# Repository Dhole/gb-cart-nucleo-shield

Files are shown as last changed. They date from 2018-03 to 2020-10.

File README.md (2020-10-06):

# Game Boy Cart NUCLEO Shield

## Description

This is the design of a Shield for NUCLEO STM32 development boards (also known
as STM32 NUCLEO Morpho) to connect Game Boy cartridges.

This PCB is meant to be used with my Game Boy Cart reader/writer:

- [gb-rw-stm32f411](https://github.com/Dhole/gb-rw-stm32f411)
- [gb-rw-host](https://github.com/Dhole/gb-rw-host)

## Pictures

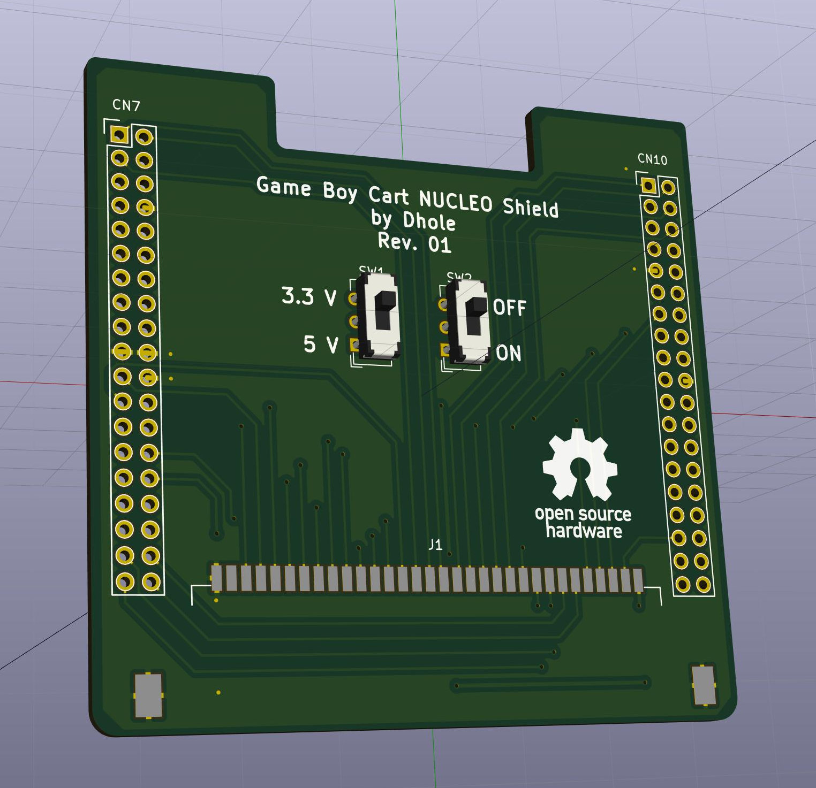
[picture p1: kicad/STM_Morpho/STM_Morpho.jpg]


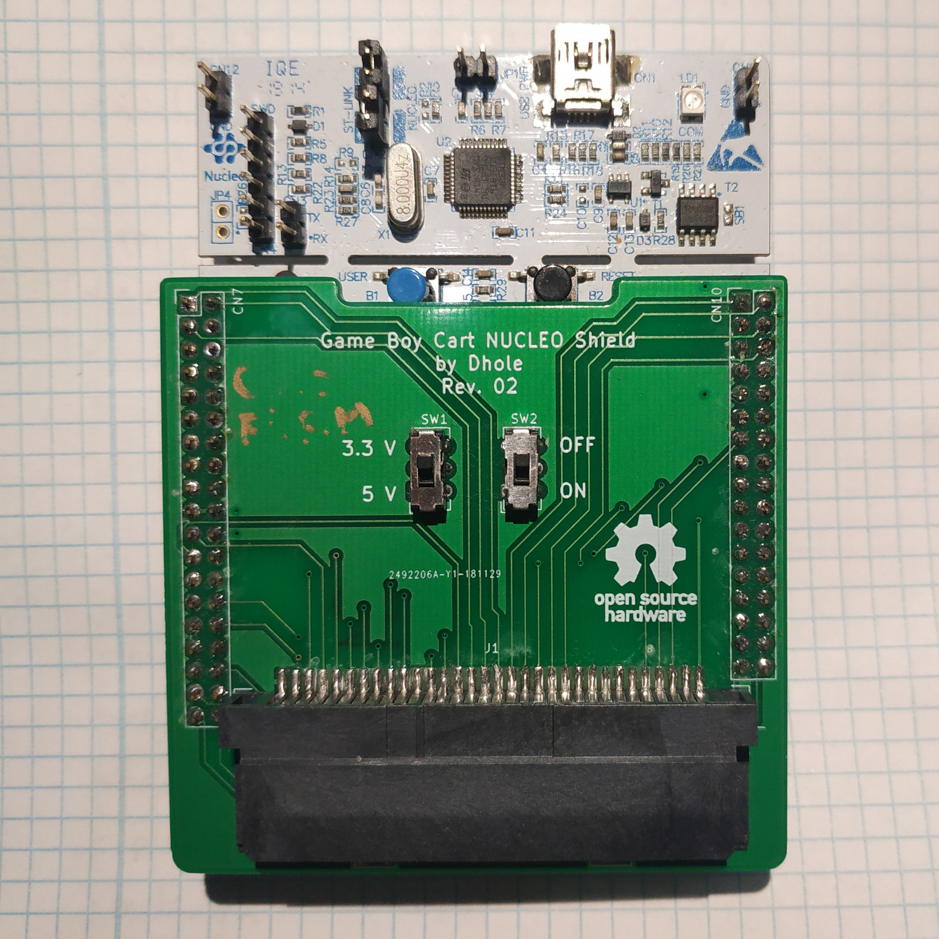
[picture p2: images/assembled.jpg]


## Components

Prices are estimations taken from AliExpress (except when stated explicitly)

- 2 x 6 pin toggle switch (~ 2 x 1.3 EUR / 10)

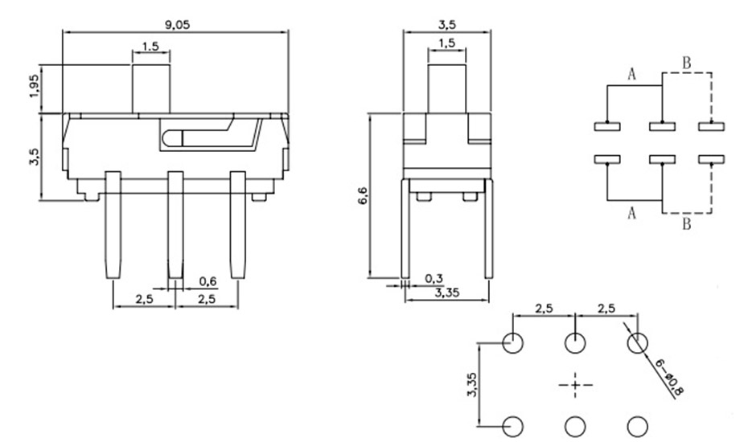
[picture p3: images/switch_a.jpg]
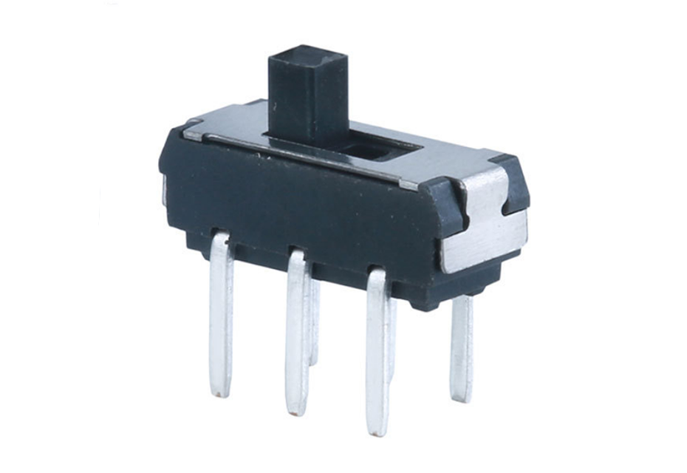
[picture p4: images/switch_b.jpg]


- 2 x 40 pin header connector strip, 2.54m spacing (~ 2 x 1.03 EUR / 10)
  - You will need to cut the strips into: 2 x 17 pins, 2 x 19 pins

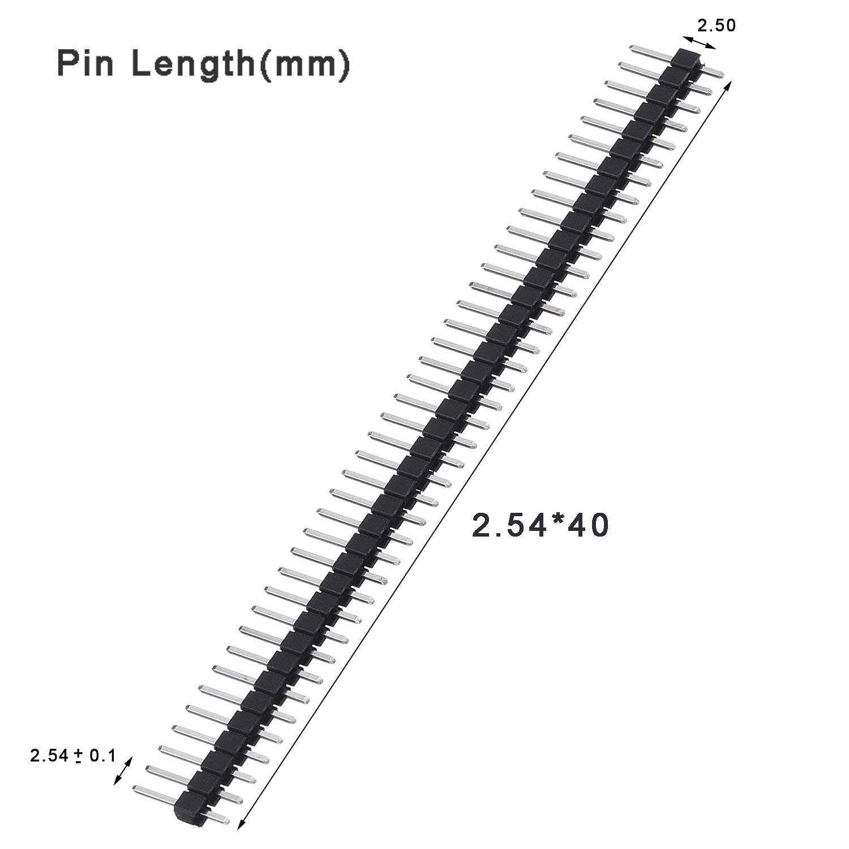
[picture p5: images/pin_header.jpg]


- 1 x GBA slot (~ 1 x 7.02 EUR / 5)

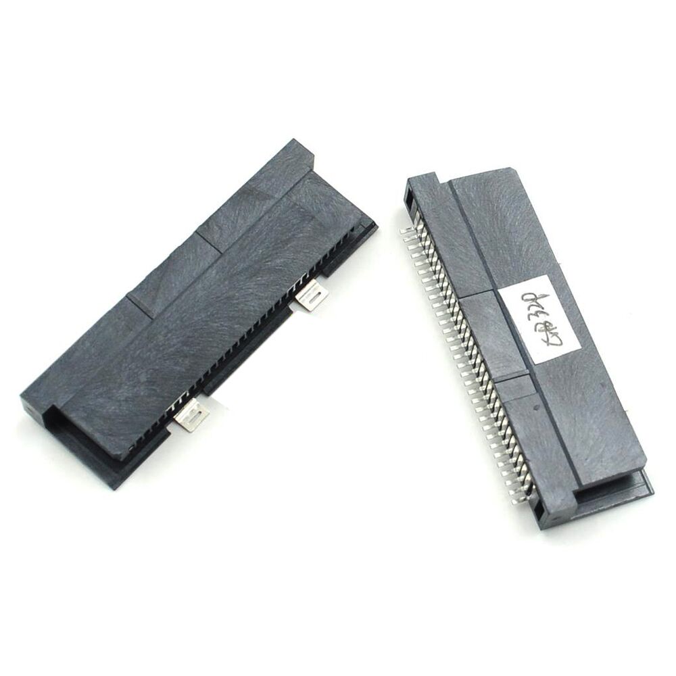
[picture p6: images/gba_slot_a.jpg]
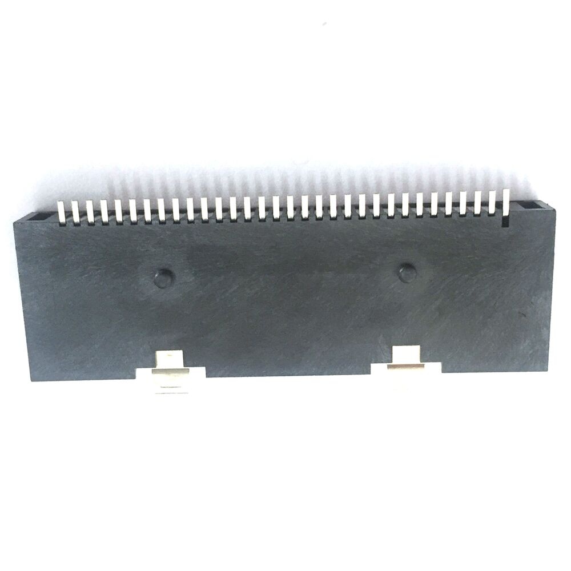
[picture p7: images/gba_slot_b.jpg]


The firmware is implemented to work on the NUCLEO-F411RE

- 1 x NUCLEO-F411RE (1 x 11.48 EUR at [eu.mouser.com](https://eu.mouser.com))

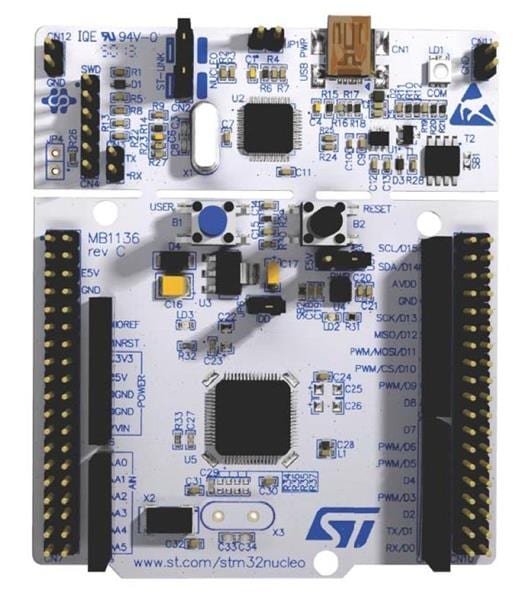
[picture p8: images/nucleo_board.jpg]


I ordered the manufacture of the board at JLCPCB with great results
- 1 x 2 layer PCB board (~ 1 x 10 EUR / 10 with shipping included in 2018)

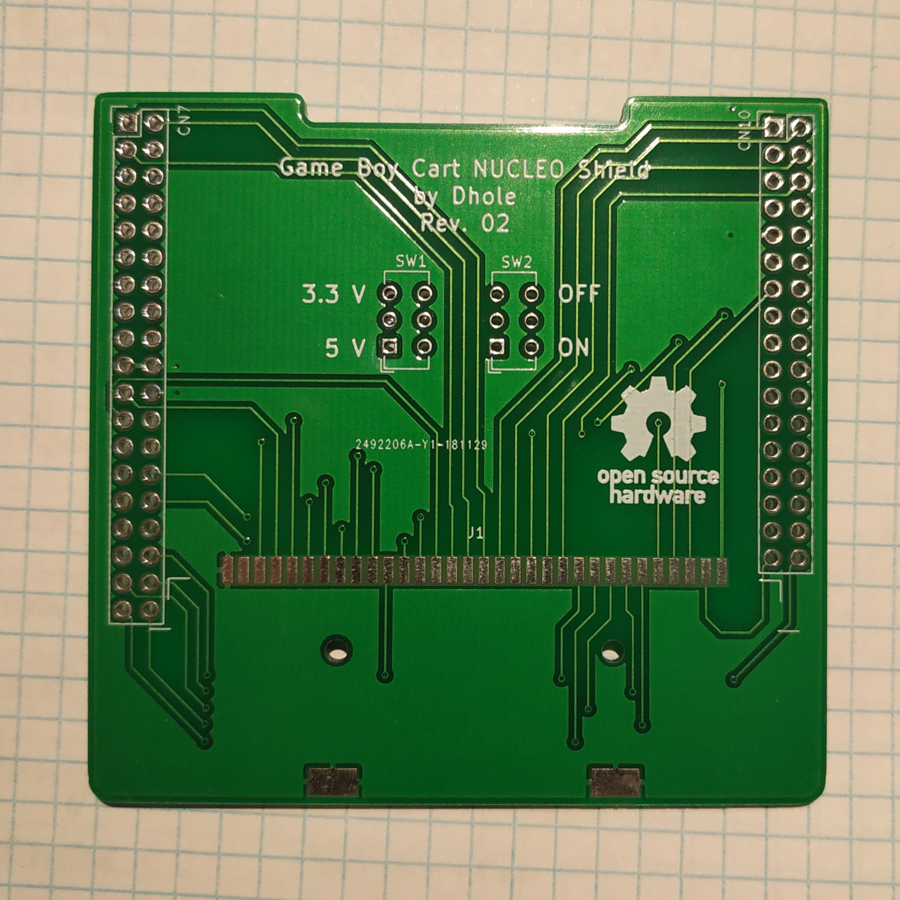
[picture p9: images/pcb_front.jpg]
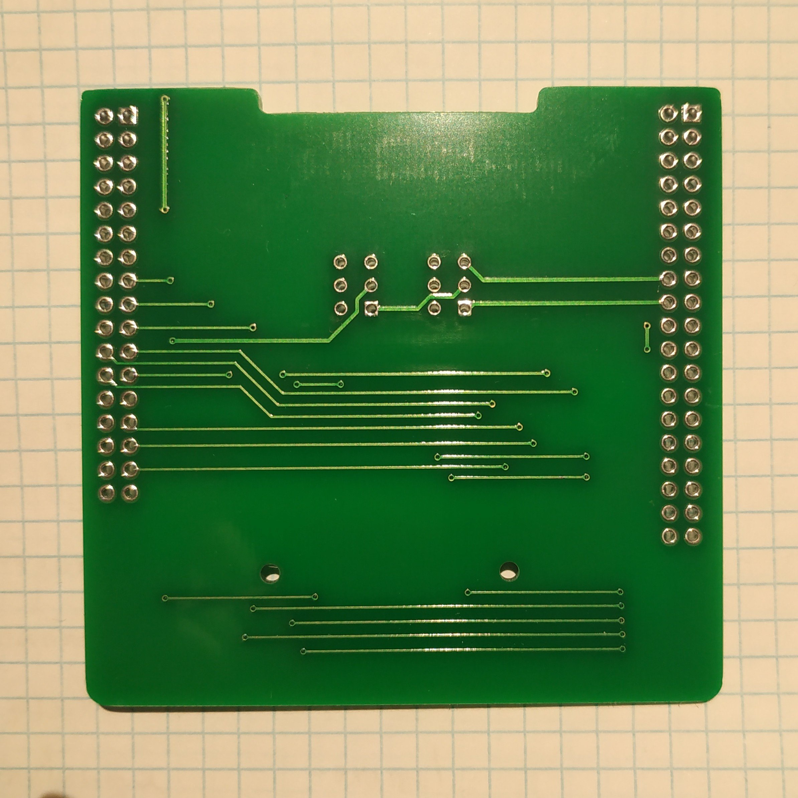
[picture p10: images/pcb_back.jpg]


## Attributions

The design this PCB is based on an [STM32 NUCLEO Morpho template made by
mobilinkd](https://github.com/mobilinkd/stm-morpho-template) published under
the MIT License.

The Game Boy cartridge slot component used in the PCB is taken from the [KiCad libraries by gekkio](https://github.com/Gekkio/gekkio-kicad-libs) published under the 
[Creative Commons Attribution license](https://creativecommons.org/licenses/by/4.0/)

## License

I'm publishing the rest of the work under the [Creative Commons Attribution-ShareAlike license](https://creativecommons.org/licenses/by-sa/4.0/).



**CC BY-SA**

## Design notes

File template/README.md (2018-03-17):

# stm-morpho-template

https://github.com/mobilinkd/stm-morpho-template

KiCad Template for STM32 Nucleo-64 Expansion Boards

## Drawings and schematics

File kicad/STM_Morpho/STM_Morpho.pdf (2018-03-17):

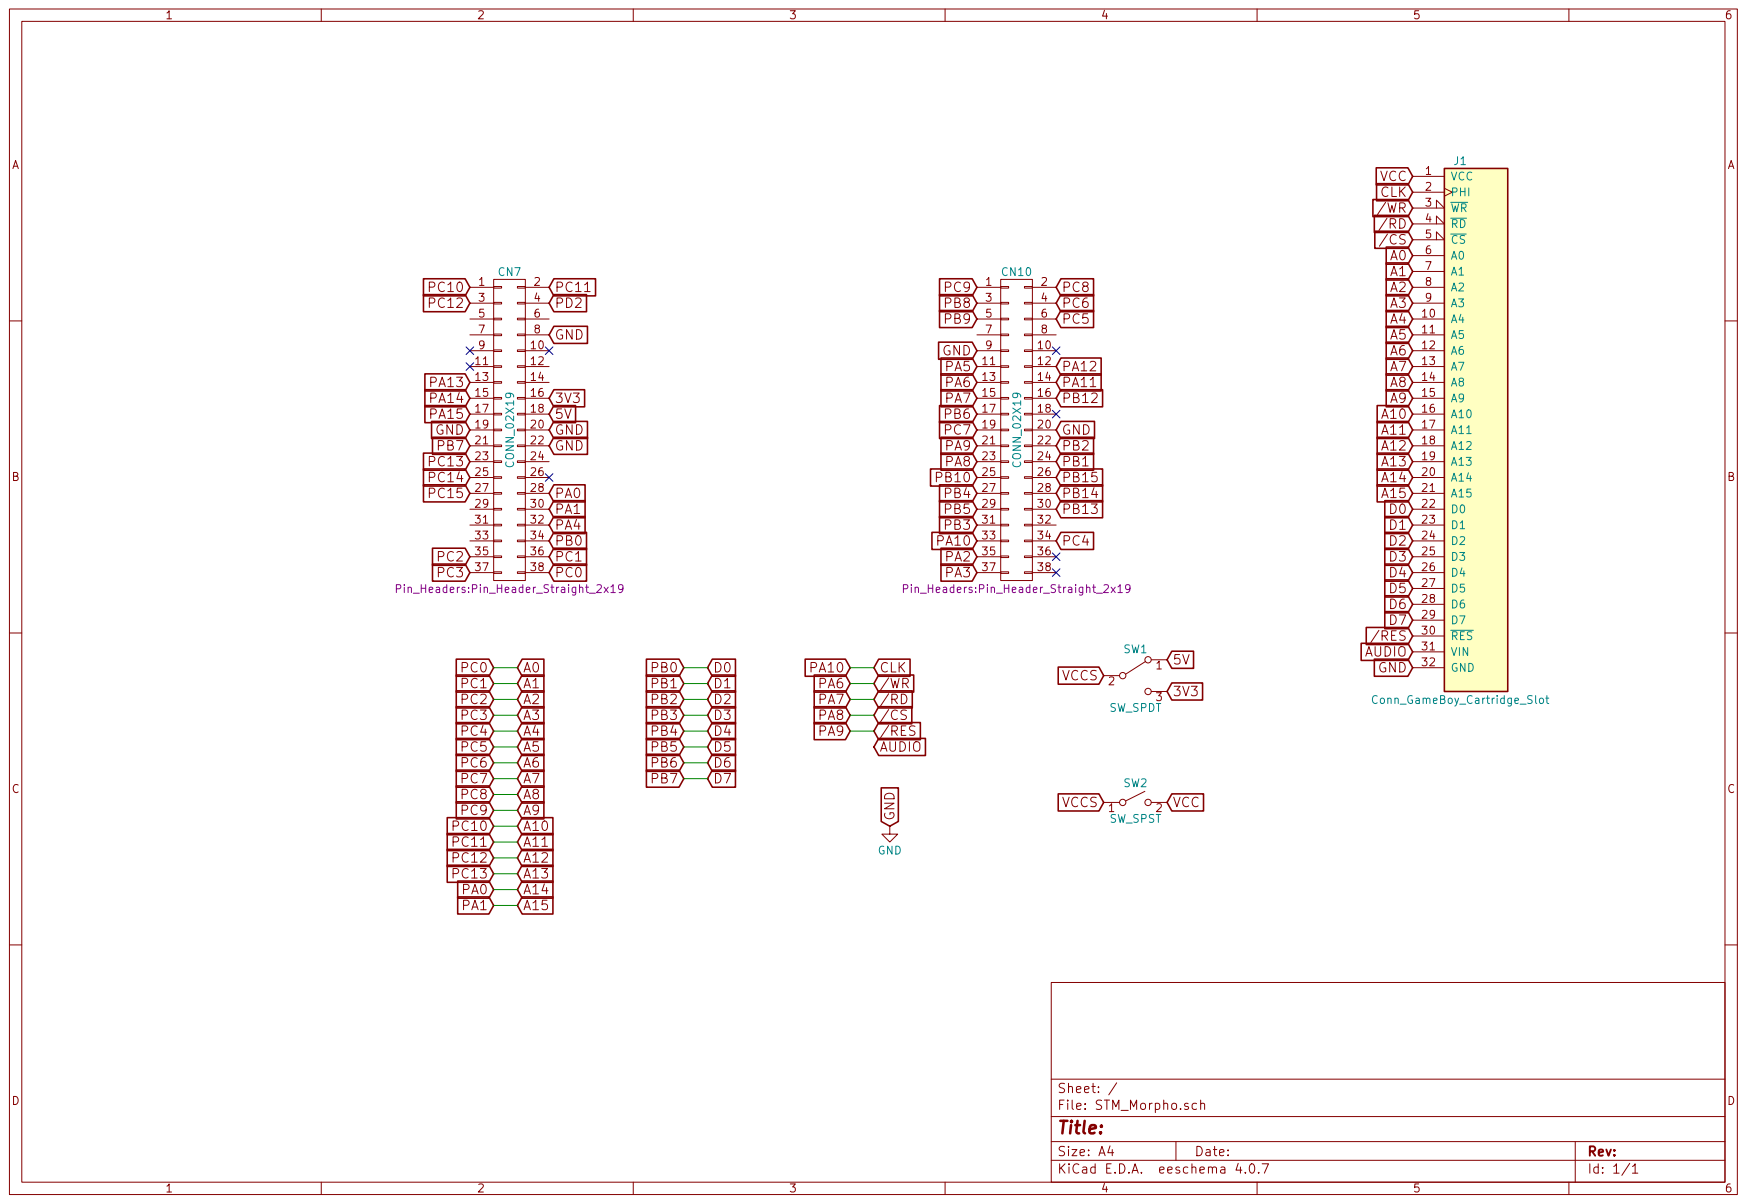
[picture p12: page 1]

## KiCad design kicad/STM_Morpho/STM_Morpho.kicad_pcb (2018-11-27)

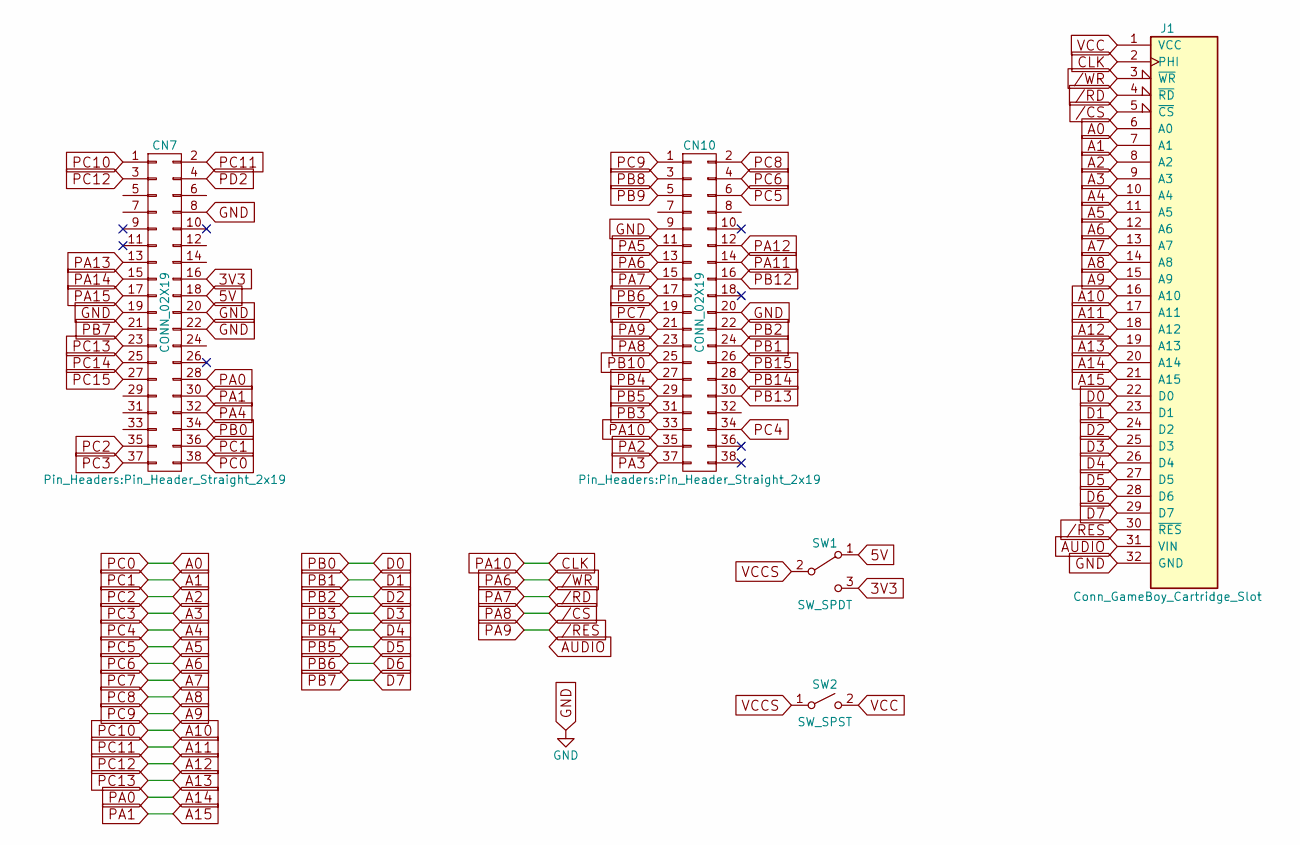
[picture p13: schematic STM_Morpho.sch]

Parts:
CN7, CN10: CONN_02X19; Pin_Header_Straight_2x19
J1: Conn_GameBoy_Cartridge_Slot; GameBoy_Cartridge_Slot_DSLite
SW1: SW_SPDT; SW_CuK_JS202011CQN_DPDT_Straight
SW2: SW_SPST; SW_CuK_JS202011CQN_DPDT_Straight

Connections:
3V3: CN7.16, SW1.3 (C)
5V: CN7.18, SW1.1 (A)
/CS: CN10.23, J1.5 (~CS)
/RD: CN10.15, J1.4 (~RD)
/RES: CN10.21, J1.30 (~RES)
/WR: CN10.13, J1.3 (~WR)
A0: CN7.38, J1.6 (A0)
A1: CN7.36, J1.7 (A1)
A2: CN7.35, J1.8 (A2)
A3: CN7.37, J1.9 (A3)
A4: CN10.34, J1.10 (A4)
A5: CN10.6, J1.11 (A5)
A6: CN10.4, J1.12 (A6)
A7: CN10.19, J1.13 (A7)
A8: CN10.2, J1.14 (A8)
A9: CN10.1, J1.15 (A9)
A10: CN7.1, J1.16 (A10)
A11: CN7.2, J1.17 (A11)
A12: CN7.3, J1.18 (A12)
A13: CN7.23, J1.19 (A13)
A14: CN7.28, J1.20 (A14)
A15: CN7.30, J1.21 (A15)
AUDIO: J1.31 (VIN)
CLK: CN10.33, J1.2 (PHI)
D0: CN7.34, J1.22 (D0)
D1: CN10.24, J1.23 (D1)
D2: CN10.22, J1.24 (D2)
D3: CN10.31, J1.25 (D3)
D4: CN10.27, J1.26 (D4)
D5: CN10.29, J1.27 (D5)
D6: CN10.17, J1.28 (D6)
D7: CN7.21, J1.29 (D7)
GND: CN7.8, CN7.19, CN7.20, CN7.22, CN10.9, CN10.20, J1.32 (GND)
PA4: CN7.32
PA5: CN10.11
PA11: CN10.14
PA12: CN10.12
PA13: CN7.13
PA14: CN7.15
PA15: CN7.17
PB8: CN10.3
PB9: CN10.5
PB10: CN10.25
PB12: CN10.16
PB13: CN10.30
PB14: CN10.28
PB15: CN10.26
PC14: CN7.25
PC15: CN7.27
PD2: CN7.4
VCC: J1.1 (VCC), SW2.2 (B)
VCCS: SW1.2 (B), SW2.1 (A)

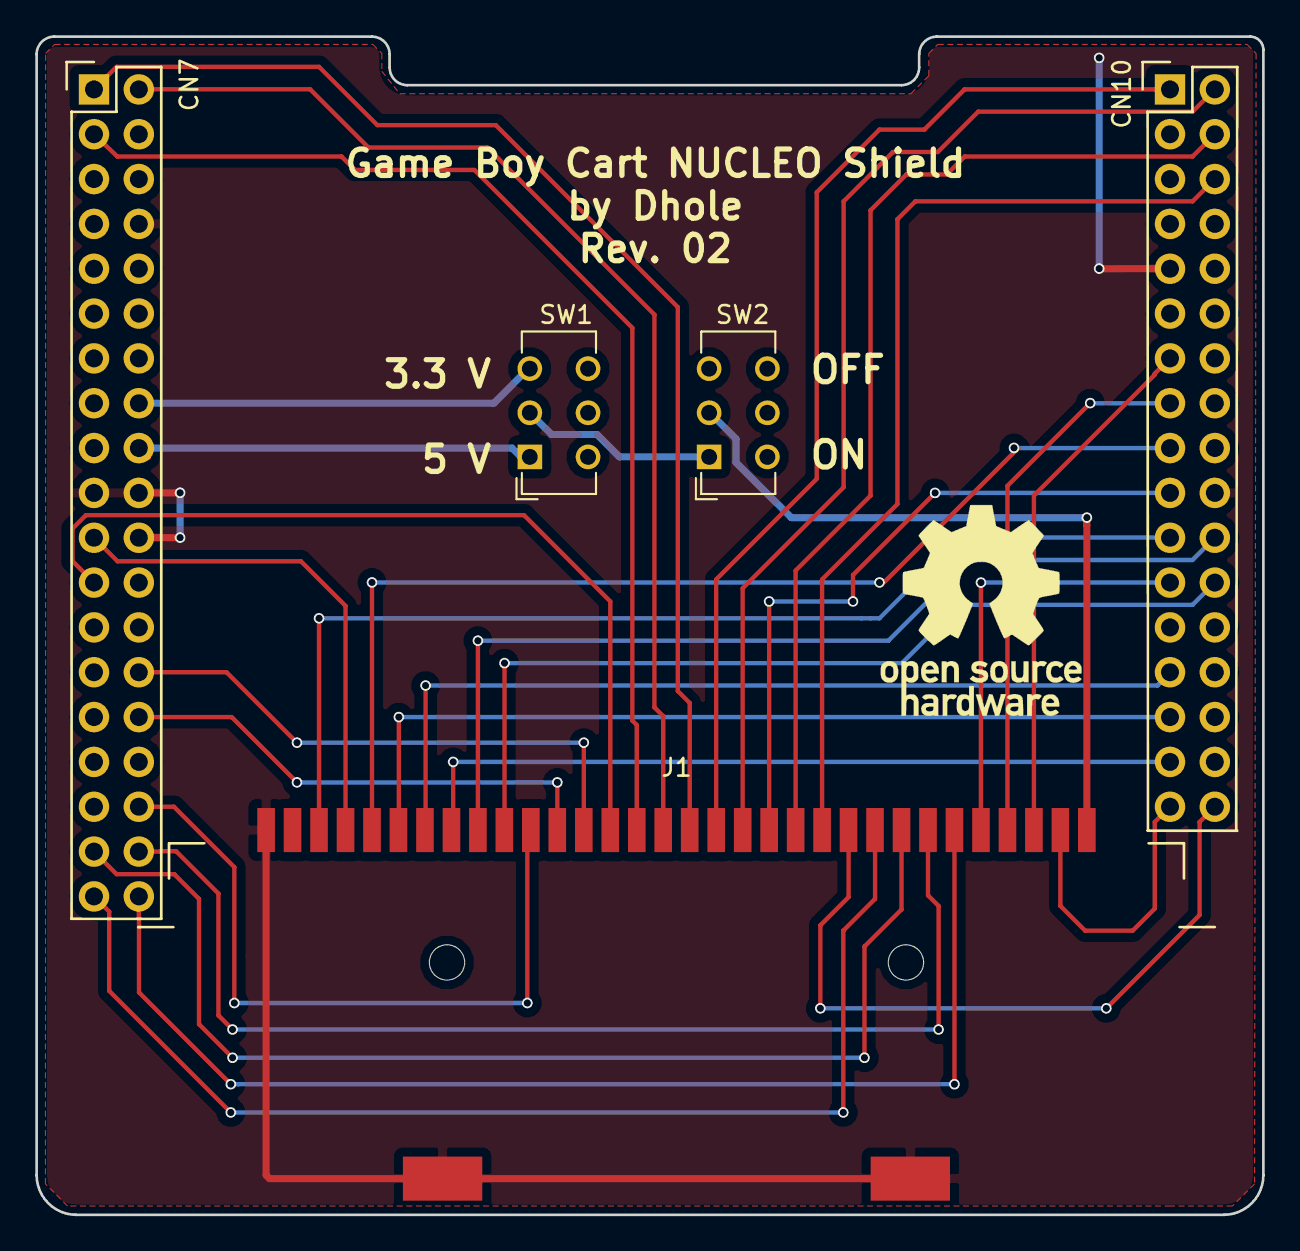
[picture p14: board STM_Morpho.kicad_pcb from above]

Board: 2 copper layers, 69.5 x 66.8 mm, 5 parts (0 on the bottom side), 34 nets.

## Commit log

2018-03-17 Use submodule for Gekkio Kicad libs
    [STM_Morpho.kicad_pcb]
2018-11-27 Use different GBA cart slot
    [STM_Morpho-2018-11-27-11-59-48.sch, STM_Morpho-2018-11-27-12-05-24.sch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]
